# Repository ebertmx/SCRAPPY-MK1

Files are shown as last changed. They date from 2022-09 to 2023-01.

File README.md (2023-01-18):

# SCRAPPY-MK1
 A 3D printed robot arm. View documents in project_files for a complete description.
 
 This arm was developed over a 4 week period as an engineering demonstration. Inspired by a previous project, HUEBERT MK2, SCRAPPY consist mostly of 3D printed components and is controllable over the internet (IoT).

SCRAPPY

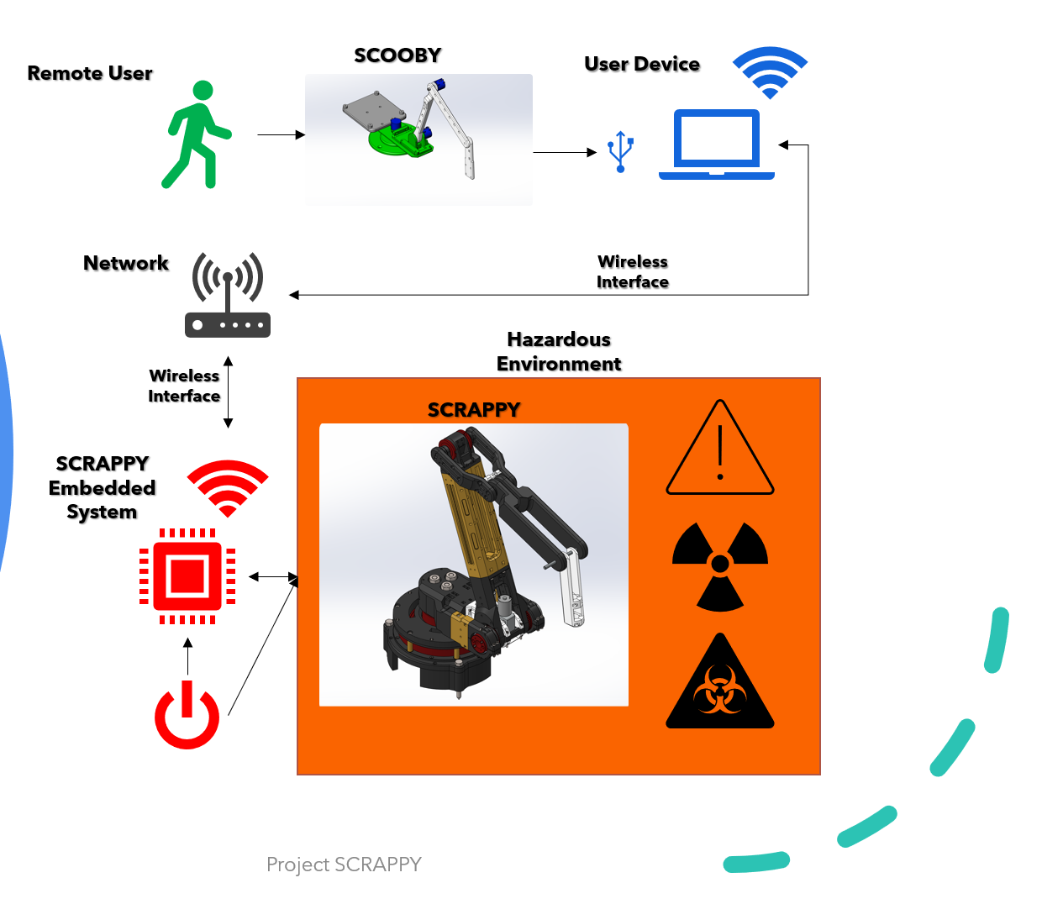
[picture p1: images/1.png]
SCRAPPY - Use Case


The goals of project SCRAPPY were too design and build a robot arm which

1. is highly modular
2. inexpensive
3. had at least 3 DoF
4. could be controlled wireless over a websocket or similar
5. was position and speed controllable
6. used a variety of electrical components (for demonstration purposes)

Other requirements of the specific design can be found in project_files.

The code contained in this respository is designed to run on a 30pin ESP32 Dev module. A python GUI interface is also contained.

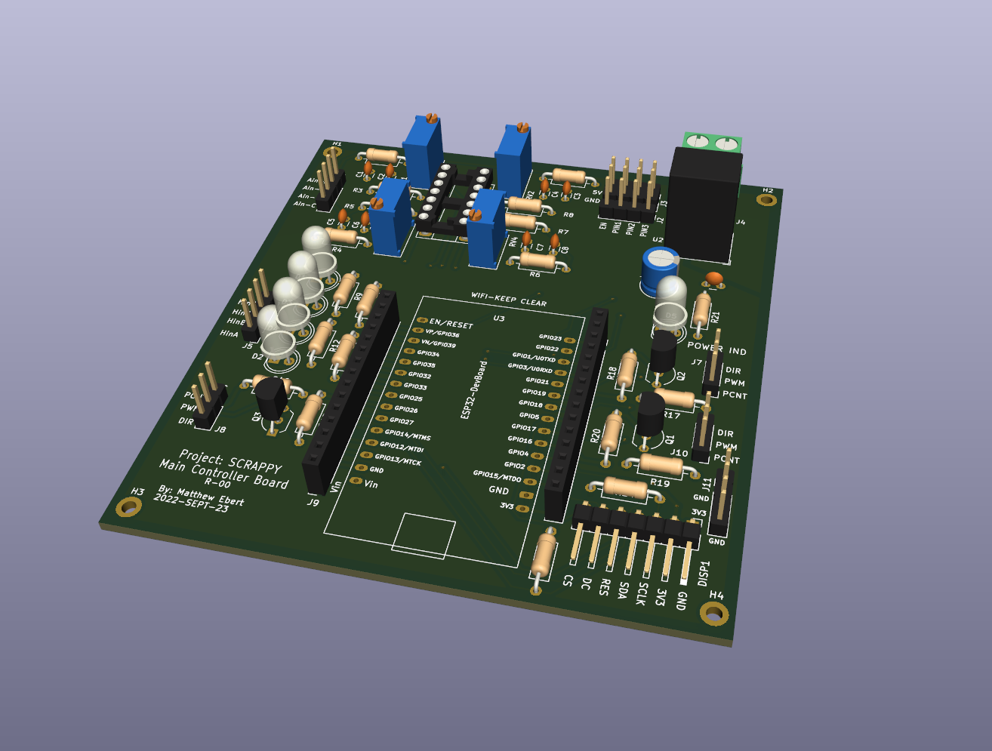
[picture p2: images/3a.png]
PCB design

Electrical
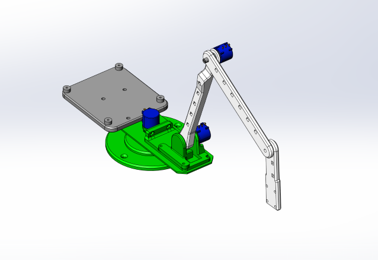
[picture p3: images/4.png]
SCOOBY

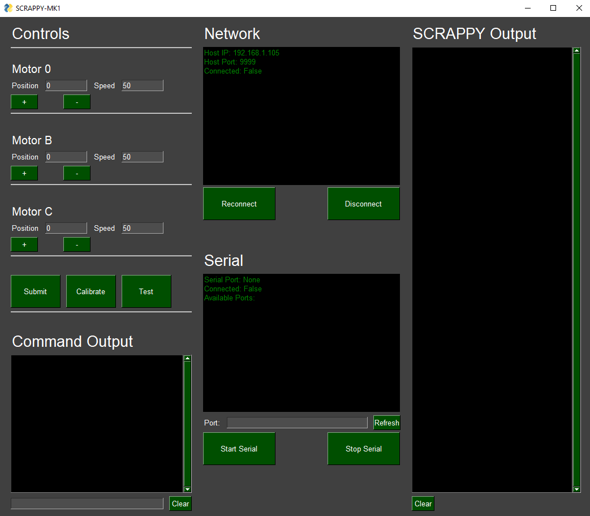
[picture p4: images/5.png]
GUI


This project is ongoing. More details on the use and implementation of this code will be posted when available.

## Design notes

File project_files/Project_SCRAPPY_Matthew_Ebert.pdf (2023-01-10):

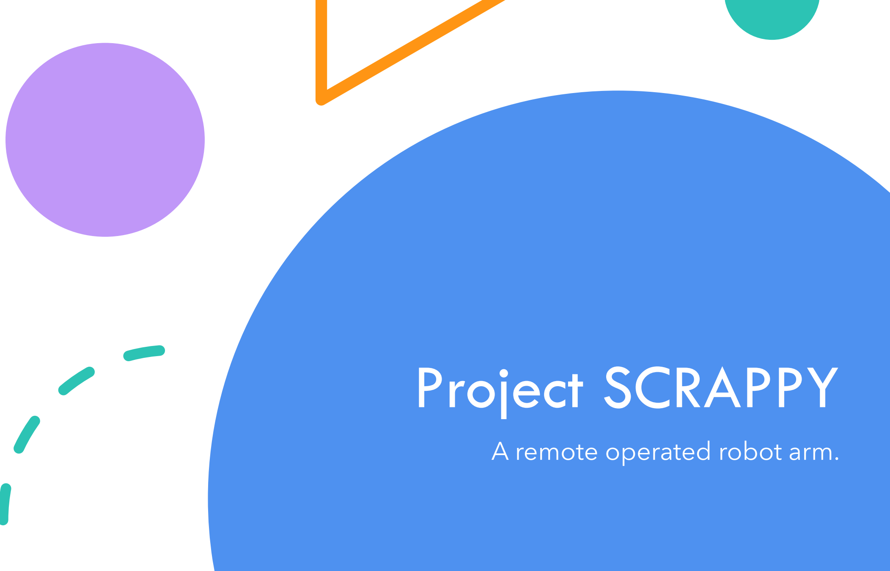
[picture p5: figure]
Project SCRAPPY; A remote operated robot arm.
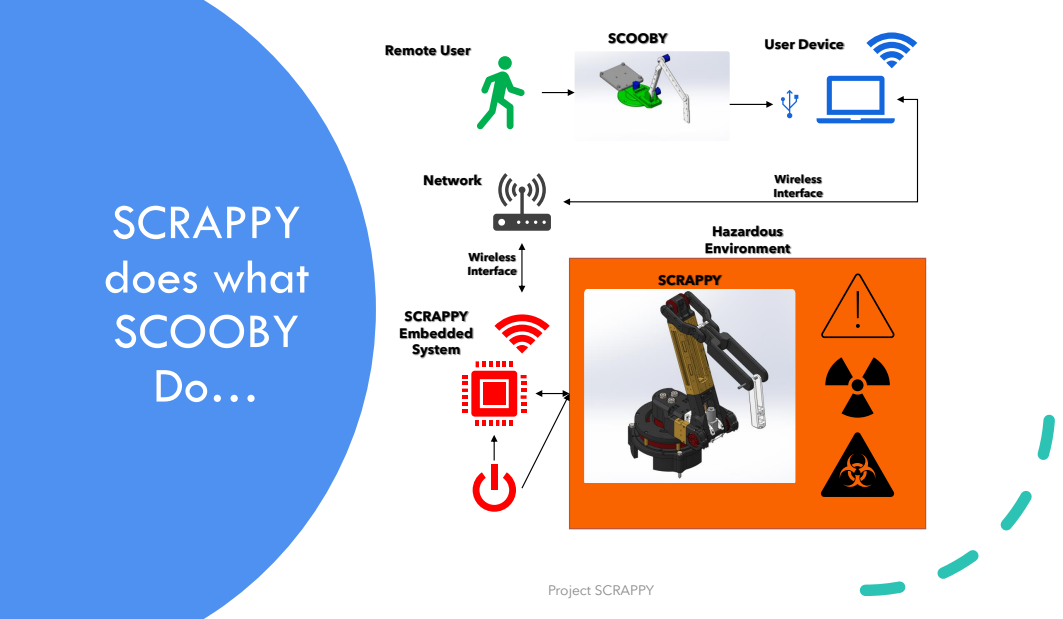
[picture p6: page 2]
SCRAPPY does what SCOOBY Do…; Project SCRAPPY; Remote User; SCOOBY; User Device; Network; SCRAPPY Embedded System; Wireless Interface; Hazardous Environment; SCRAPPY

# Applications

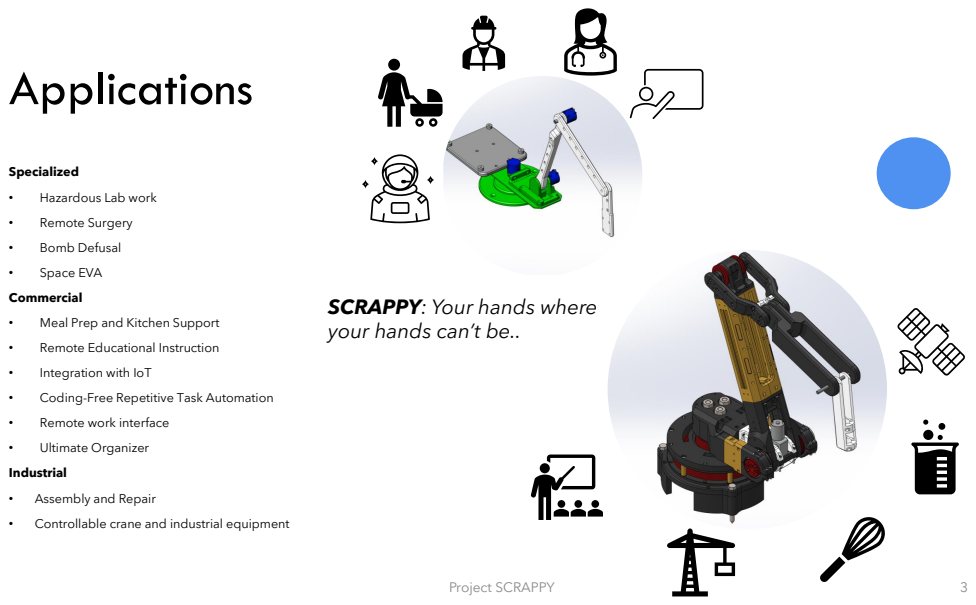
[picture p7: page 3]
Specialized; • Remote Surgery; • Bomb Defusal; • Space EVA; Commercial; • Ultimate Organizer; Industrial; Project SCRAPPY

• Hazardous Lab work

SCRAPPY: Your hands where
your hands can’t be..

• Meal Prep and Kitchen Support

• Remote Educational Instruction

• Integration with IoT

• Coding-Free Repetitive Task Automation

• Remote work interface

• Assembly and Repair

• Controllable crane and industrial equipment

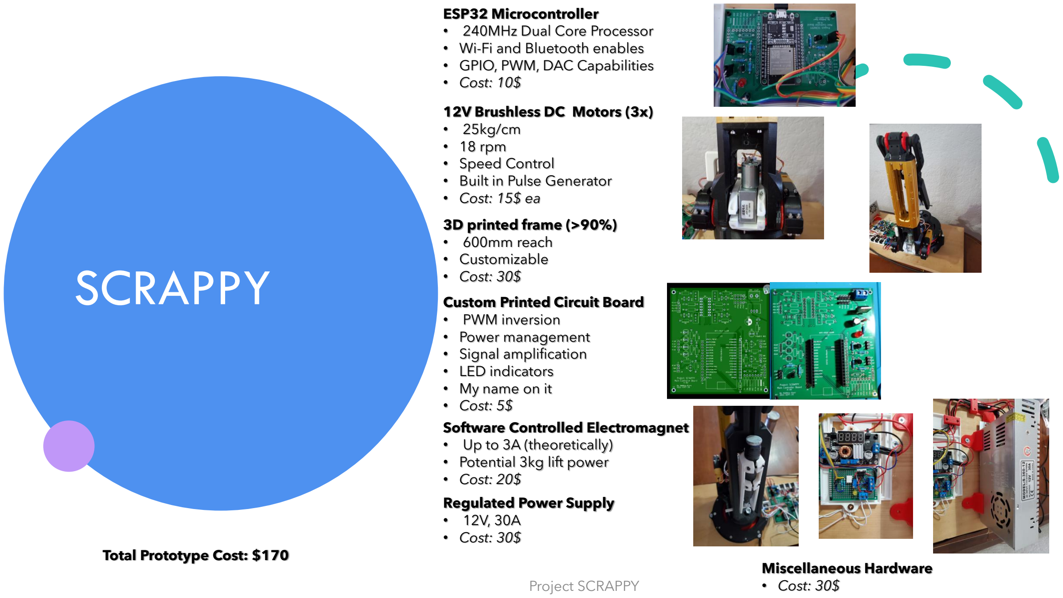
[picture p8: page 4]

# SCRAPPY

Project SCRAPPY

ESP32 Microcontroller
- 240MHz Dual Core Processor
- Wi-Fi and Bluetooth enables
- GPIO, PWM, DAC Capabilities
- Cost: 10$

3D printed frame (>90%)
- 600mm reach
- Customizable
- Cost: 30$

12V Brushless DC Motors (3x)
- 25kg/cm
- 18 rpm
- Speed Control
- Built in Pulse Generator
- Cost: 15$ ea

Custom Printed Circuit Board
- PWM inversion
- Power management
- Signal amplification
- LED indicators
- My name on it
- Cost: 5$

Regulated Power Supply
- 12V, 30A
- Cost: 30$

Miscellaneous Hardware
- Cost: 30$

Software Controlled Electromagnet
- Up to 3A (theoretically)
- Potential 3kg lift power
- Cost: 20$

Total Prototype Cost: $170

# SCRAPPY Design

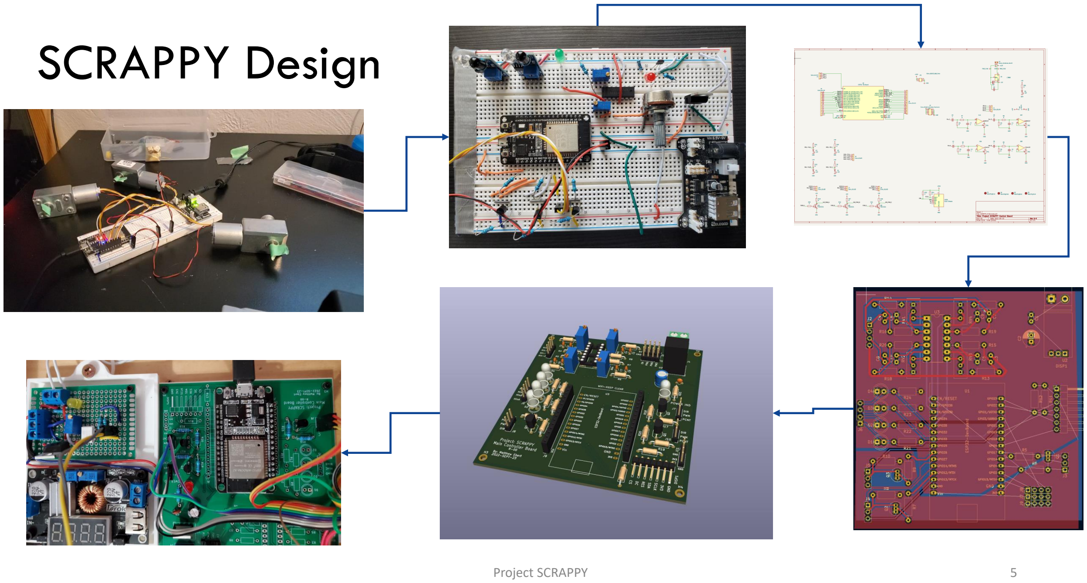
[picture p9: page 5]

# SCRAPPY Design

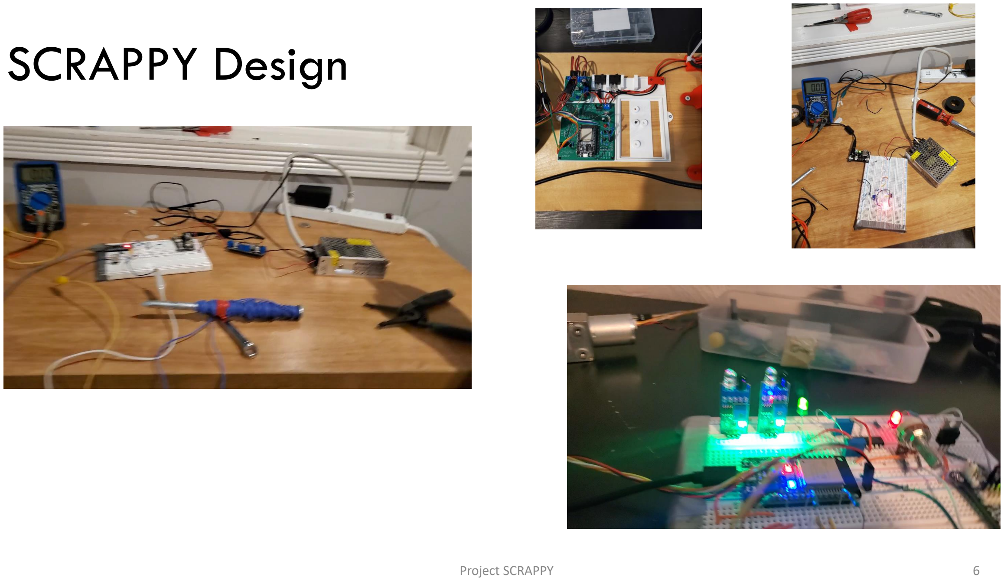
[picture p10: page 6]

# SCRAPPY ASSEBMLY

## 3D printing: Like drawing or writing –

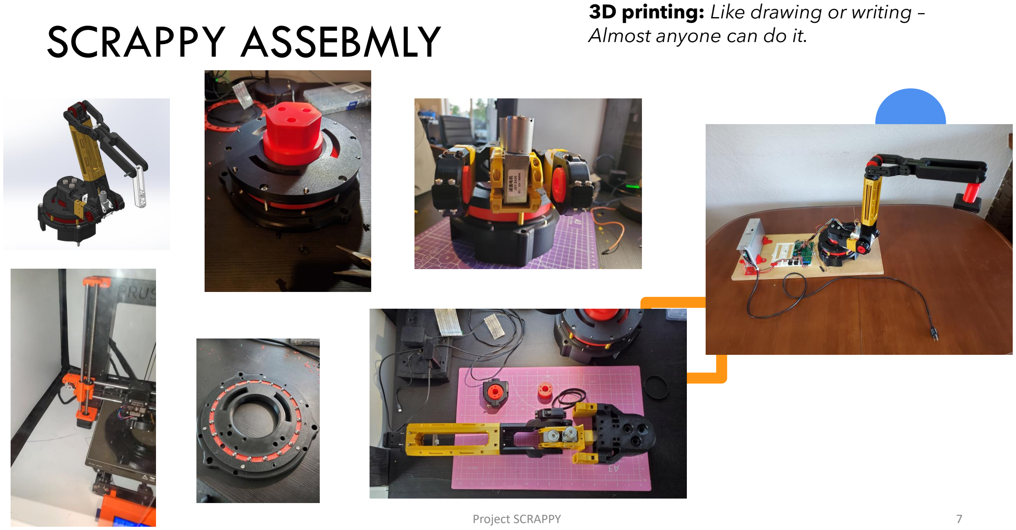
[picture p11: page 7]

Almost anyone can do it.

# User Interface: SCOOBY

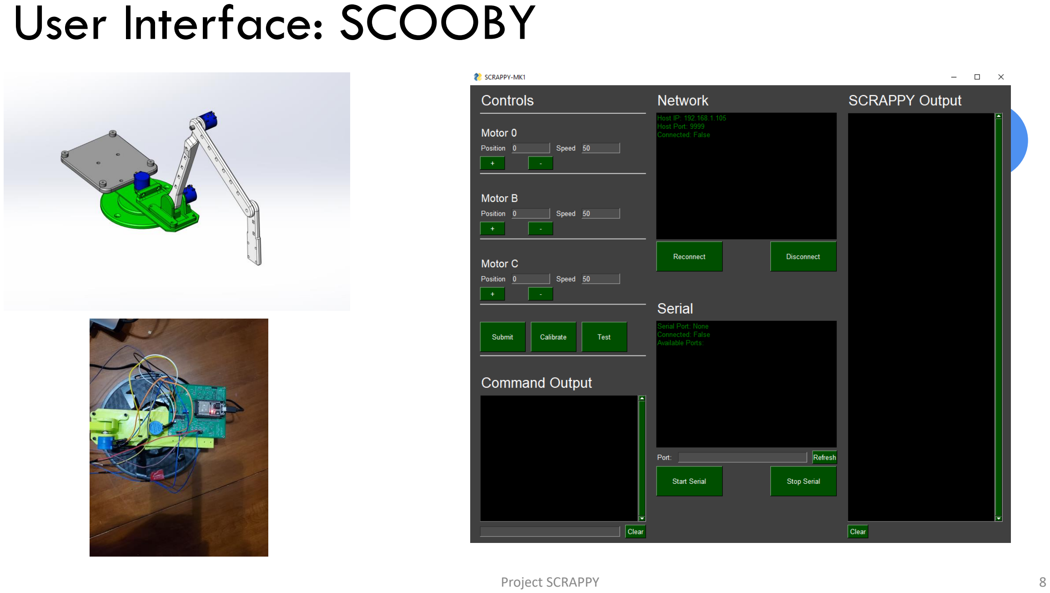
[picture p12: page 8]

# SCRAPPY and ECE

# Mechanically, Scrappy isn’t that

interesting.

# - Very little mechanical analysis needed - 3D printed makes design simple and fast

## This is the easy stuff - no background knowledge required…

# Mecha-tronics is mostly ‘electronics’ - Microcontrollers - Embedded Programming - Motor Control - Power Management - Signal Amplification processing - Control theory

## This is the important stuff- SCRAPPY doesn’t do

anything if this isn’t done right.

# At some point “Engineering is Engineering”

# What do you want to learn… - Microcontrollers and digital design - Control theory - Circuit analysis - Motors and Power electronics - Signal Processing - Material Properties and Quantum

Physics (if you are crazy).

THEN | What do you want to do with it…

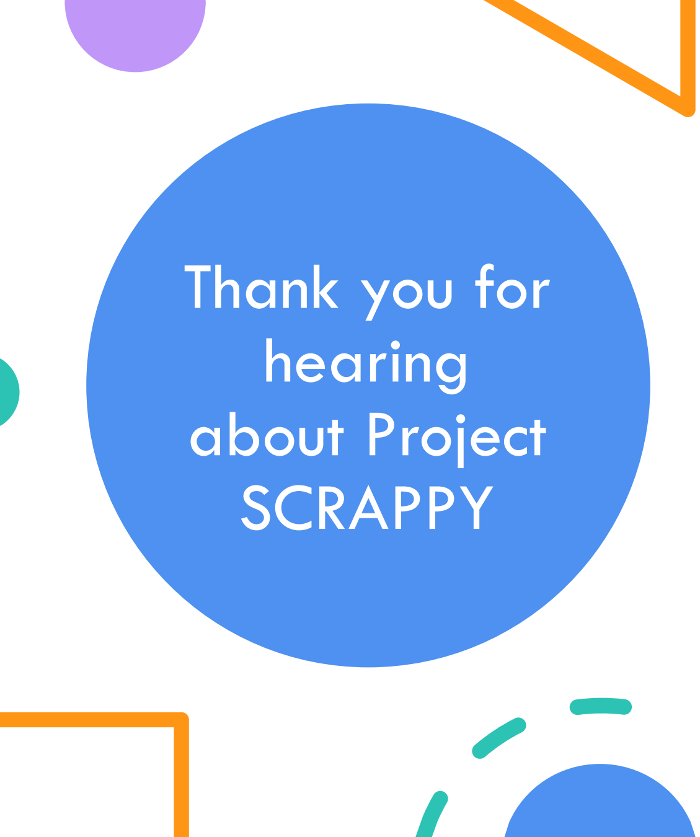
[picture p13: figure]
Thank you for hearing about Project SCRAPPY

# SCRAPPY will be on GitHub Soon at : ebertmx

# Question, Comments, and Feedback

Welcome.

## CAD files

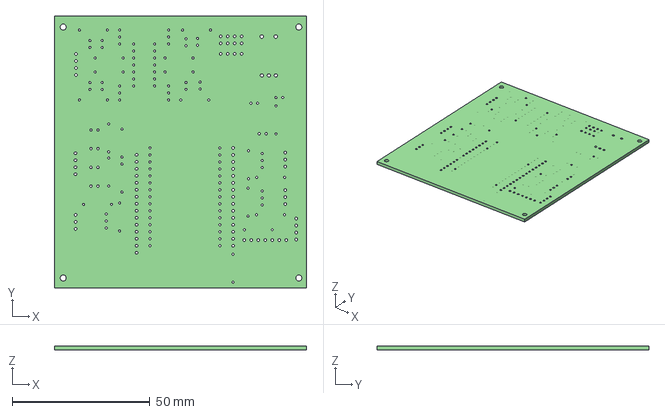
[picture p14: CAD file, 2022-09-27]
Hardware/Electrical/SCRAPPY_PCB/SCRAPPY_PCB.step
91.6 x 98.7 x 1.60 mm

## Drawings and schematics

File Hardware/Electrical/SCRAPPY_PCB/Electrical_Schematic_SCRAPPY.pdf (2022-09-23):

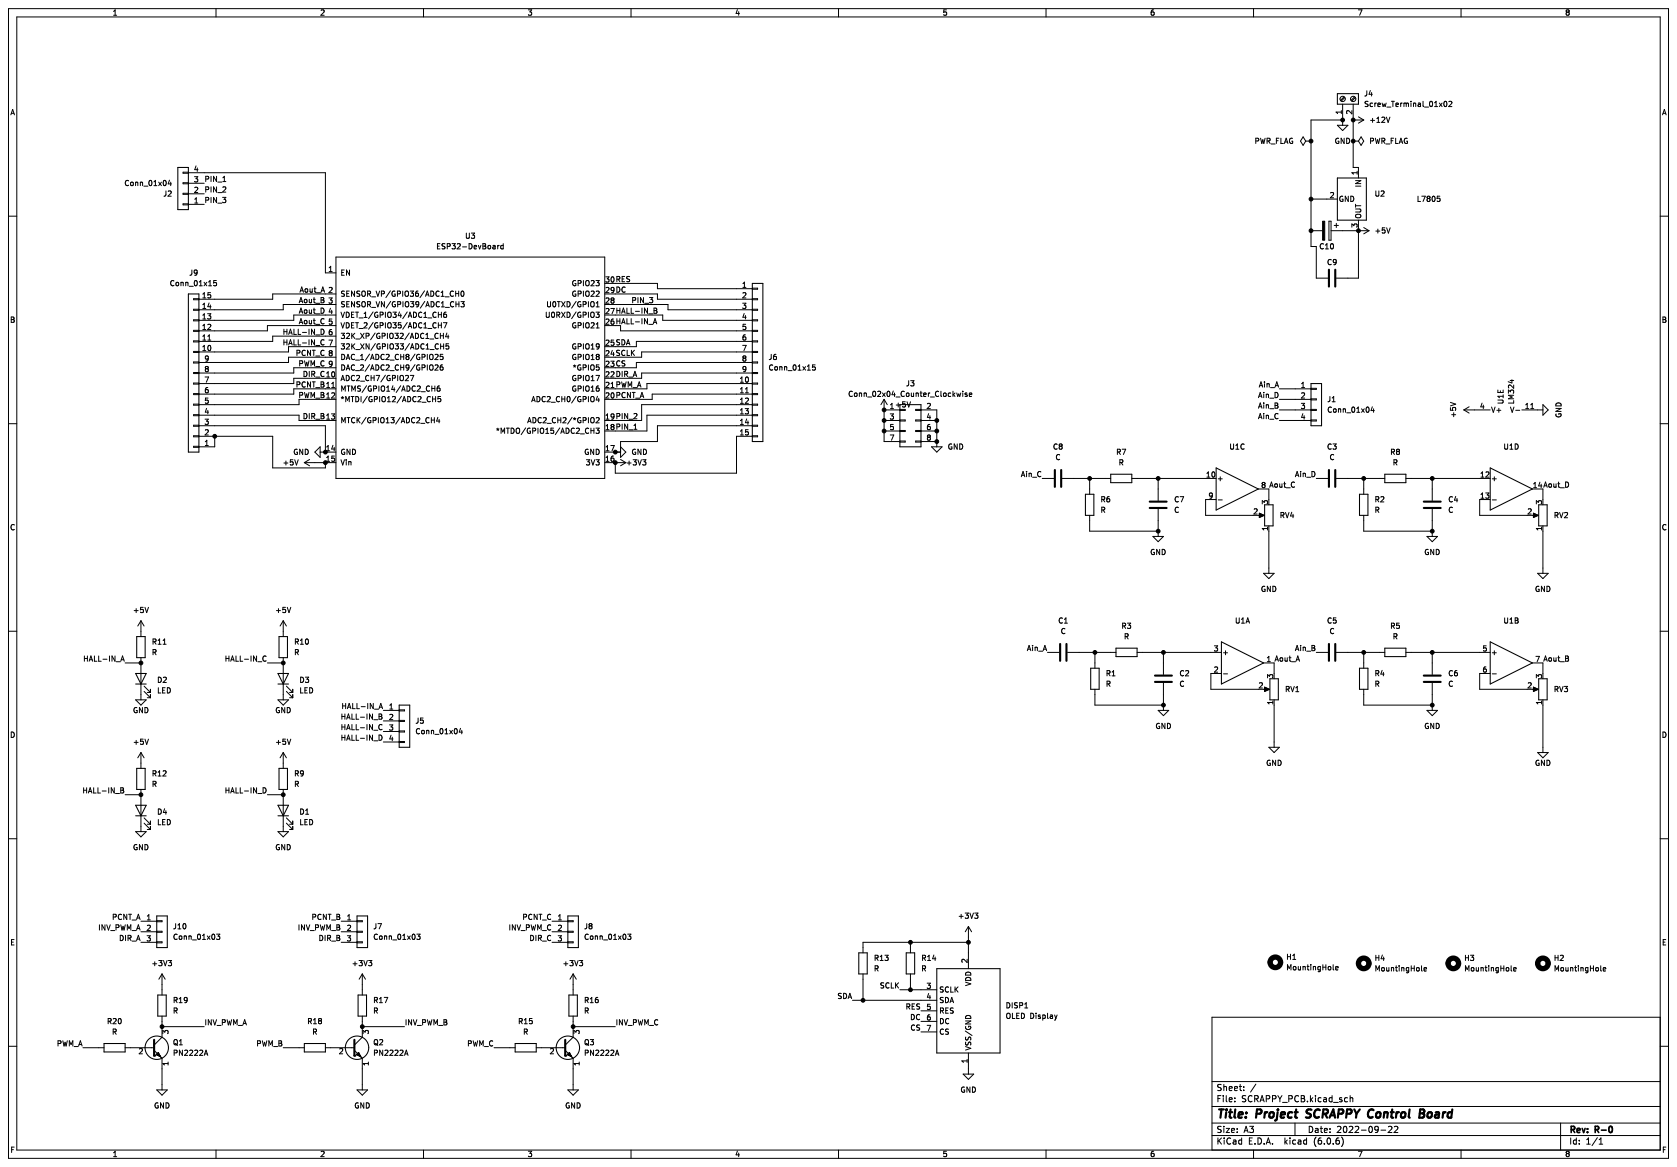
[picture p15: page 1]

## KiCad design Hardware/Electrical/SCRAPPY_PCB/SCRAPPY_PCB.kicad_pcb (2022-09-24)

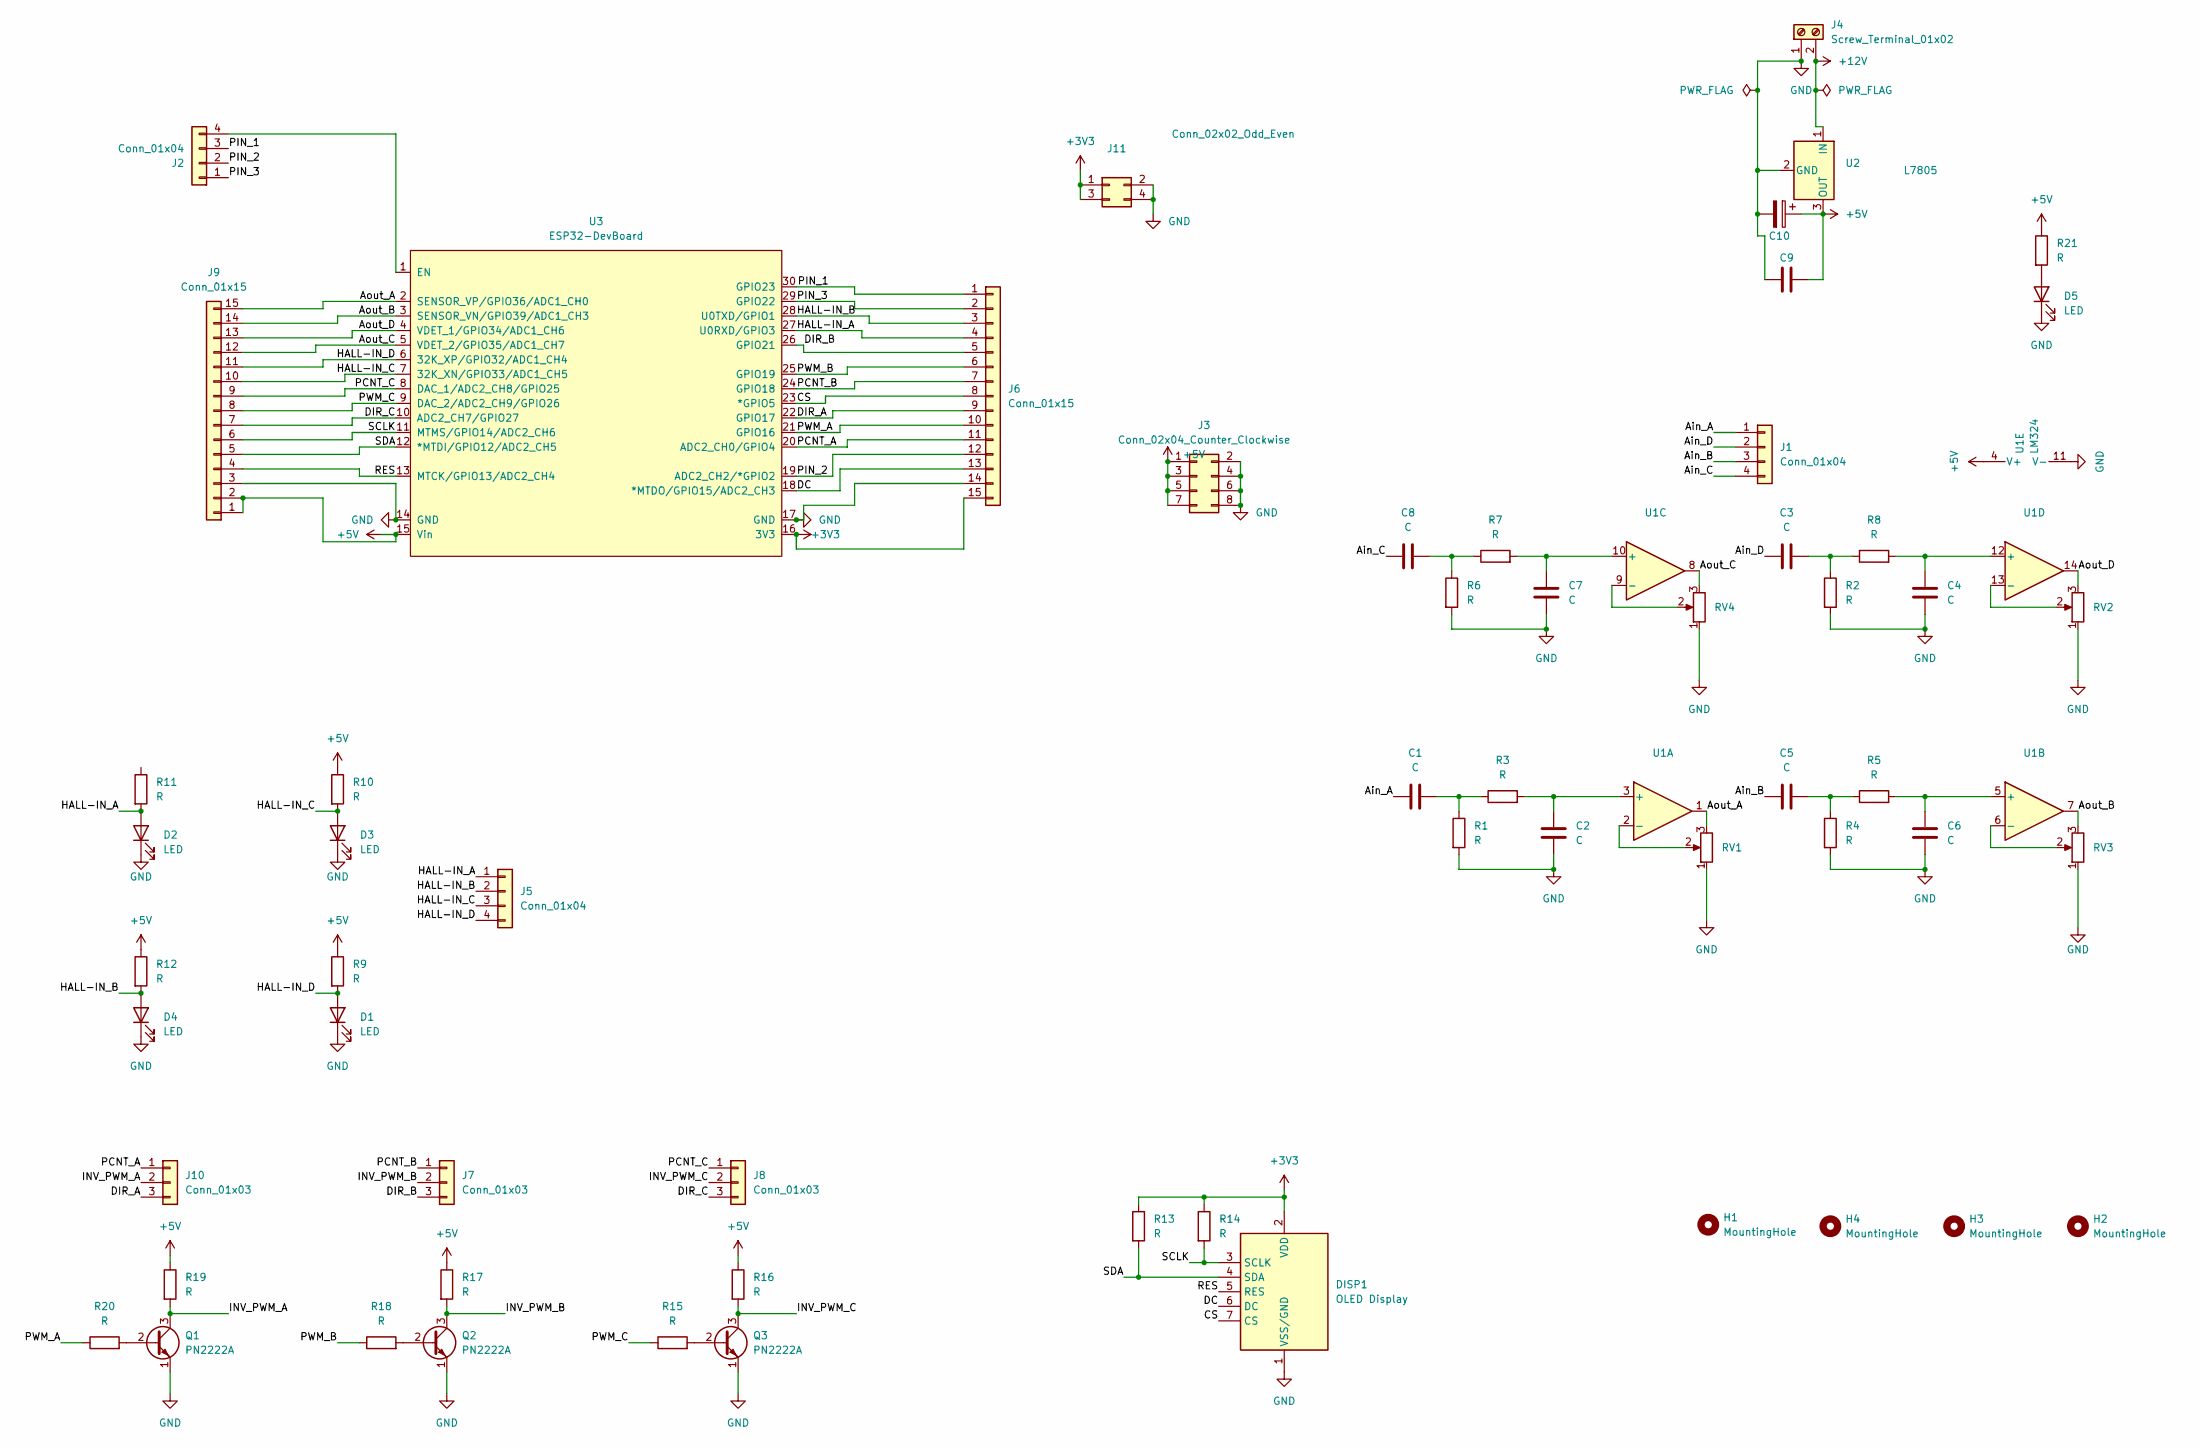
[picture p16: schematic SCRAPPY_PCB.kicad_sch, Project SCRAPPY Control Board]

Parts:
C1, C2, C3, C4, C5, C6, C7, C8, C9: C; C_Disc_D3.0mm_W1.6mm_P2.50mm
C10: C_Polarized; CP_Radial_D6.3mm_P2.50mm
D1, D2, D3, D4, D5: LED; LED_D5.0mm_Clear
DISP1: OLED Display; PinHeader_1x07_P2.54mm_Horizontal
H1, H2, H3, H4: MountingHole; MountingHole_2.2mm_M2_DIN965_Pad
J1, J2, J5: Conn_01x04; PinHeader_1x04_P2.54mm_Vertical
J3: Conn_02x04_Counter_Clockwise; PinHeader_2x04_P2.54mm_Vertical
J4: Screw_Terminal_01x02; TerminalBlock_Phoenix_MKDS-1,5-2-5.08_1x02_P5.08mm_Horizont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
J6, J9: Conn_01x15; PinSocket_1x15_P2.54mm_Vertical
J7, J8, J10: Conn_01x03; PinHeader_1x03_P2.54mm_Vertical
J11: Conn_02x02_Odd_Even; PinHeader_1x04_P2.54mm_Vertical
Q1, Q2, Q3: PN2222A; TO-92_Inline_Wide
R1, R2, R3, R4, R5, R6, R7, R8, R9, R10, R11, R12, R13, R14, R15, R16, R17, R18, R19, R20, R21: R; R_Axial_DIN0207_L6.3mm_D2.5mm_P10.16mm_Horizontal
RV1, RV2, RV3, RV4: R_Potentiometer; Potentiometer_Bourns_3296W_Vertical
U1: LM324; DIP-14_W7.62mm_Socket_LongPads
U2: L7805; Converter_DCDC_RECOM_R-78B-2.0_THT
U3: ESP32-DevBoard

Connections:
+3V3: DISP1.2 (VDD), J6.15, J11.1, J11.3, R13.1, R14.1, U3.16 (3V3)
+5V: C9.2, C10.1, J3.1, J3.3, J3.5, J3.7, J9.1, J9.2, R9.1, R10.1, R12.1, R16.1, R17.1, R19.1, R21.1, U1.4 (V+), U2.3 (OUT), U3.15 (Vin)
+12V: J4.2, U2.1 (IN)
/Ain_A: C1.1, J1.1
/Ain_B: C5.1, J1.3
/Ain_C: C8.1, J1.4
/Ain_D: C3.1, J1.2
/Aout_A: J9.15, RV1.3, U1.1, U3.2 (SENSOR_VP/GPIO36/ADC1_CH0)
/Aout_B: J9.14, RV3.3, U1.7, U3.3 (SENSOR_VN/GPIO39/ADC1_CH3)
/Aout_C: J9.12, RV4.3, U1.8, U3.5 (VDET_2/GPIO35/ADC1_CH7)
/Aout_D: J9.13, RV2.3, U1.14, U3.4 (VDET_1/GPIO34/ADC1_CH6)
/CS: DISP1.7 (CS), J6.8, U3.23 (*GPIO5)
/DC: DISP1.6 (DC), J6.13, U3.18 (*MTDO/GPIO15/ADC2_CH3)
/DIR_A: J6.9, J10.3, U3.22 (GPIO17)
/DIR_B: J6.5, J7.3, U3.26 (GPIO21)
/DIR_C: J8.3, J9.7, U3.10 (ADC2_CH7/GPIO27)
/HALL-IN_A: D2.2 (A), J5.1, J6.4, R11.2, U3.27 (U0RXD/GPIO3)
/HALL-IN_B: D4.2 (A), J5.2, J6.3, R12.2, U3.28 (U0TXD/GPIO1)
/HALL-IN_C: D3.2 (A), J5.3, J9.10, R10.2, U3.7 (32K_XN/GPIO33/ADC1_CH5)
/HALL-IN_D: D1.2 (A), J5.4, J9.11, R9.2, U3.6 (32K_XP/GPIO32/ADC1_CH4)
/INV_PWM_A: J10.2, Q1.3 (C), R19.2
/INV_PWM_B: J7.2, Q2.3 (C), R17.2
/INV_PWM_C: J8.2, Q3.3 (C), R16.2
/PCNT_A: J6.11, J10.1, U3.20 (ADC2_CH0/GPIO4)
/PCNT_B: J6.7, J7.1, U3.24 (GPIO18)
/PCNT_C: J8.1, J9.9, U3.8 (DAC_1/ADC2_CH8/GPIO25)
/PIN_1: J2.3, J6.1, U3.30 (GPIO23)
/PIN_2: J2.2, J6.12, U3.19 (ADC2_CH2/*GPIO2)
/PIN_3: J2.1, J6.2, U3.29 (GPIO22)
/PWM_A: J6.10, R20.1, U3.21 (GPIO16)
/PWM_B: J6.6, R18.1, U3.25 (GPIO19)
/PWM_C: J9.8, R15.1, U3.9 (DAC_2/ADC2_CH9/GPIO26)
/RES: DISP1.5 (RES), J9.4, U3.13 (MTCK/GPIO13/ADC2_CH4)
/SCLK: DISP1.3 (SCLK), J9.6, R14.2, U3.11 (MTMS/GPIO14/ADC2_CH6)
/SDA: DISP1.4 (SDA), J9.5, R13.2, U3.12 (*MTDI/GPIO12/ADC2_CH5)
GND: C2.1, C4.1, C6.1, C7.1, C9.1, C10.2, D1.1 (K), D2.1 (K), D3.1 (K), D4.1 (K), D5.1 (K), DISP1.1 (VSS/GND), J3.2, J3.4, J3.6, J3.8, J4.1, J6.14, J9.3, J11.2, J11.4, Q1.1 (E), Q2.1 (E), Q3.1 (E), R1.2, R2.2, R4.2, R6.2, RV1.1, RV2.1, RV3.1, RV4.1, U1.11 (V-), U2.2 (GND), U3.14 (GND), U3.17 (GND)
unnamed: C1.2, R1.1, R3.1
unnamed: C2.2, R3.2, U1.3 (+)
unnamed: C3.2, R2.1, R8.1
unnamed: C4.2, R8.2, U1.12 (+)
unnamed: C5.2, R4.1, R5.1
unnamed: C6.2, R5.2, U1.5 (+)
unnamed: C7.2, R7.2, U1.10 (+)
unnamed: C8.2, R6.1, R7.1
unnamed: D5.2 (A), R21.2
unnamed: J2.4, U3.1 (EN)
unnamed: Q1.2 (B), R20.2
unnamed: Q2.2 (B), R18.2
unnamed: Q3.2 (B), R15.2
unnamed: RV1.2, U1.2 (-)
unnamed: RV2.2, U1.13 (-)
unnamed: RV3.2, U1.6 (-)
unnamed: RV4.2, U1.9 (-)

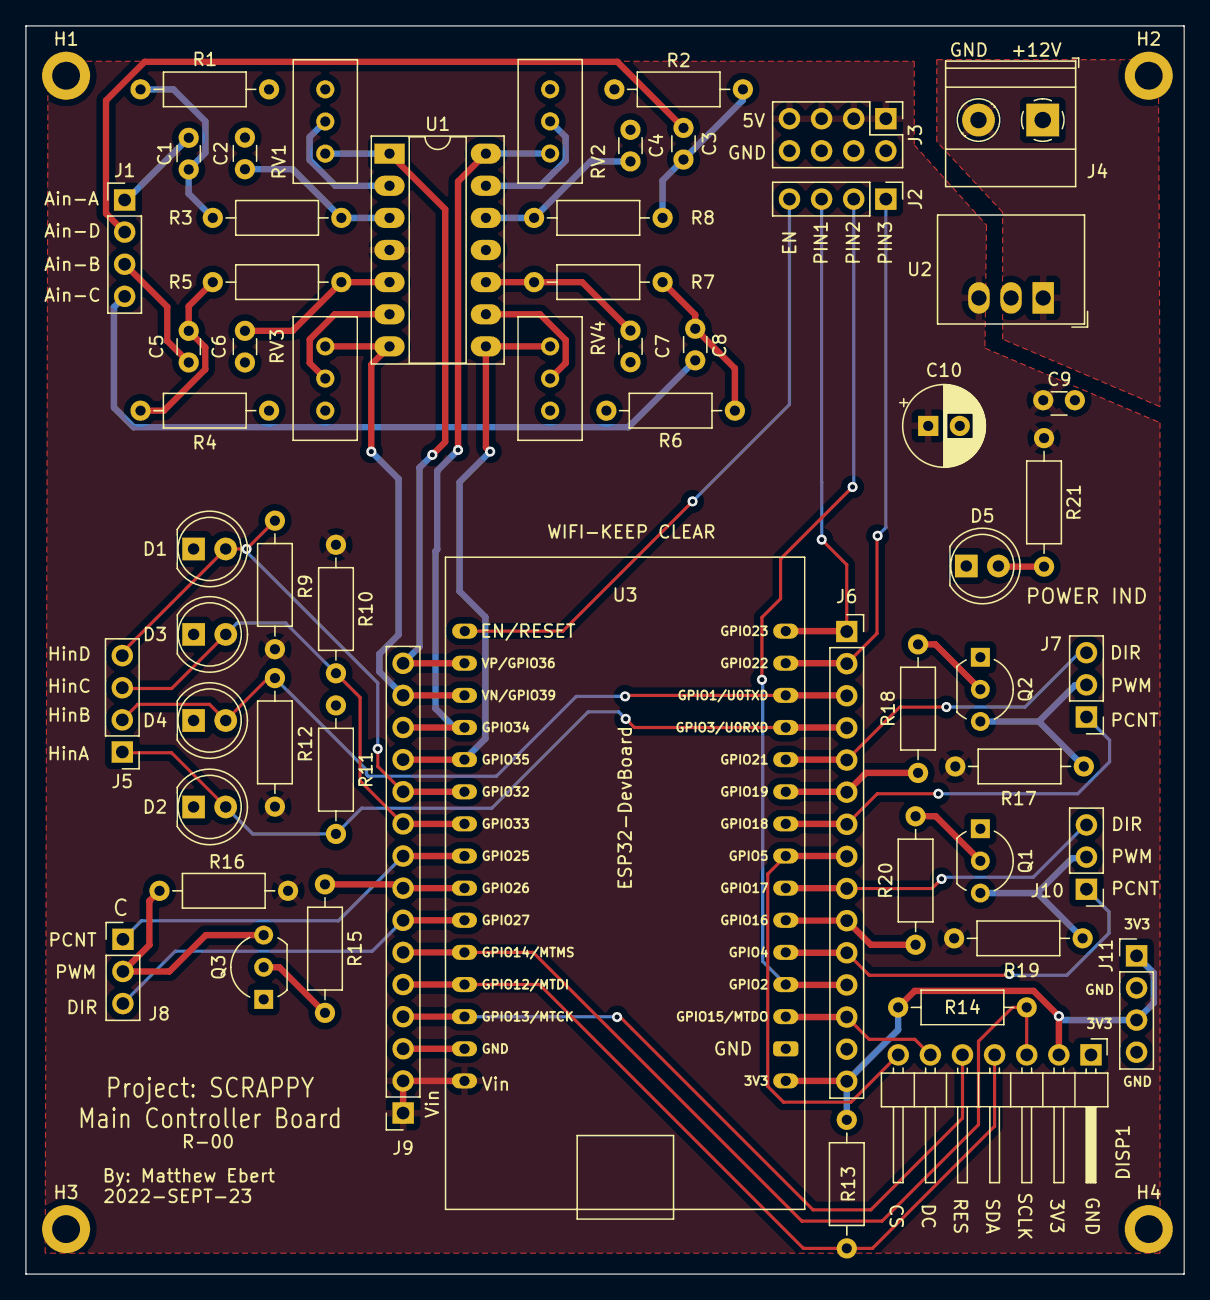
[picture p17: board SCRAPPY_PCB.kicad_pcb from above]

Board: 2 copper layers, 91.6 x 98.7 mm, 62 parts (0 on the bottom side), 53 nets.

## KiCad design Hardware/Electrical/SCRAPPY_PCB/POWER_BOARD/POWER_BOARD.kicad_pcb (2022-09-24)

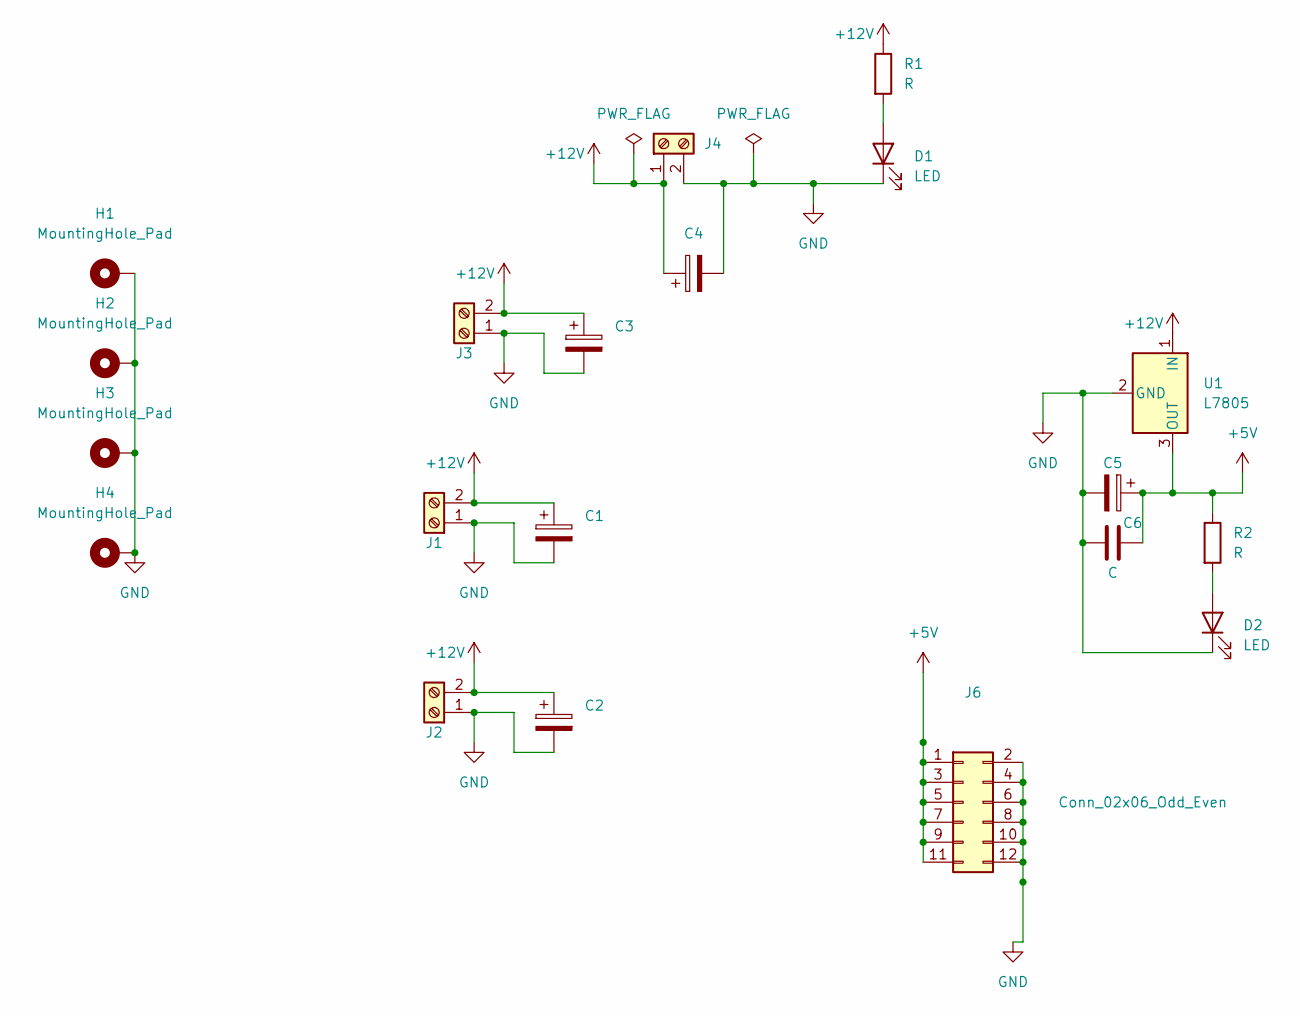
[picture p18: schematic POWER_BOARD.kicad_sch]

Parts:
C1, C2, C3, C5: C_Polarized; CP_Radial_D6.3mm_P2.50mm
C4: C_Polarized; CP_Radial_D10.0mm_P5.00mm
C6: C; C_Disc_D5.0mm_W2.5mm_P2.50mm
D1, D2: LED; LED_D5.0mm
H1, H2, H3, H4: MountingHole_Pad; MountingHole_2.2mm_M2_DIN965_Pad
J1, J2, J3, J4: Screw_Terminal_01x02; TerminalBlock_Phoenix_MKDS-1,5-2_1x02_P5.00mm_Horizontal
J6: Conn_02x06_Odd_Even; PinHeader_2x06_P2.54mm_Vertical
R1, R2: R; R_Axial_DIN0207_L6.3mm_D2.5mm_P10.16mm_Horizontal
U1: L7805; Converter_DCDC_Murata_OKI-78SR_Vertical

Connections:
+5V: C5.1, C6.2, J6.1, J6.3, J6.5, J6.7, J6.9, J6.11, R2.1, U1.3 (OUT)
+12V: C1.1, C2.1, C3.1, C4.1, J1.2, J2.2, J3.2, J4.1, R1.1, U1.1 (IN)
GND: C1.2, C2.2, C3.2, C4.2, C5.2, C6.1, D1.1 (K), D2.1 (K), H1.1, H2.1, H3.1, H4.1, J1.1, J2.1, J3.1, J4.2, J6.2, J6.4, J6.6, J6.8, J6.10, J6.12, U1.2 (GND)
unnamed: D1.2 (A), R1.2
unnamed: D2.2 (A), R2.2

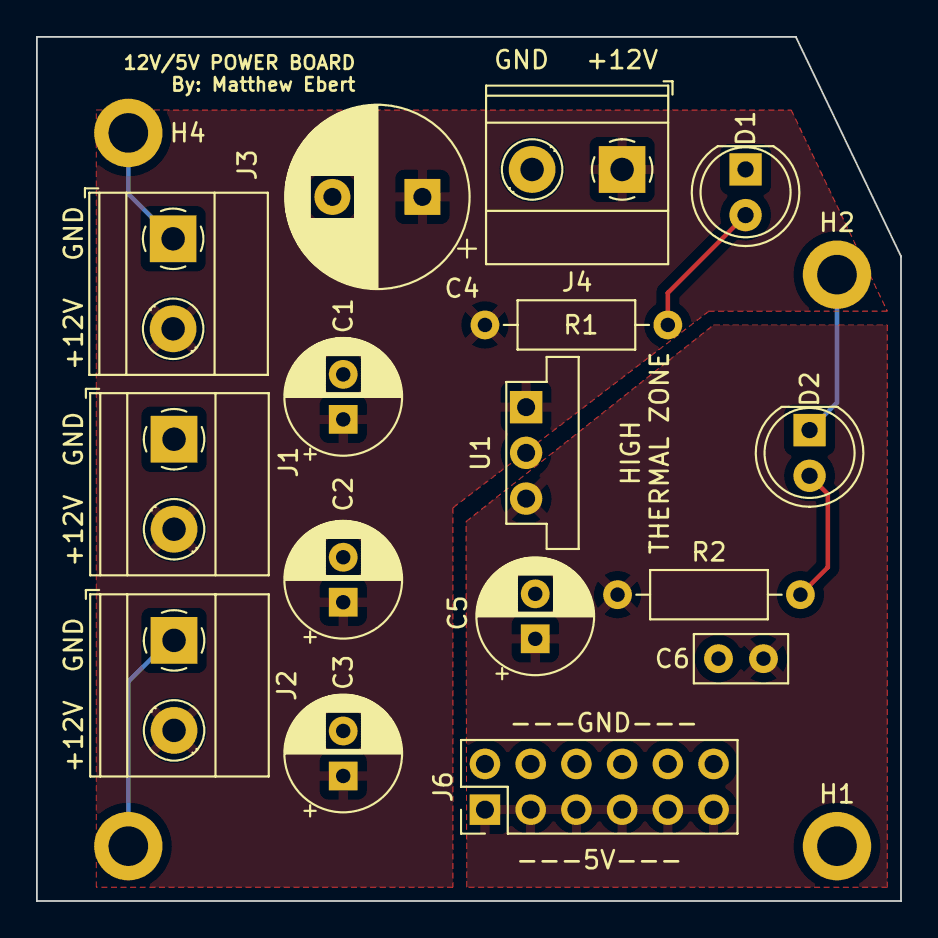
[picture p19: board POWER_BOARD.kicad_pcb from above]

Board: 2 copper layers, 48.0 x 48.0 mm, 20 parts (1 on the bottom side), 5 nets.

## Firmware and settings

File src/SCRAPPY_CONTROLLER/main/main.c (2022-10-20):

/*
 * SPDX-FileCopyrightText: 2021-2022 Espressif Systems (Shanghai) CO LTD
 *
 * SPDX-License-Identifier: Apache-2.0
 */
#include "main.h"
#include "math.h"

// GLOBALS
extern TaskHandle_t xh_MC;
extern QueueHandle_t xMC_queue;

void app_main(void)
{
    //Setup pin for magnet
     gpio_set_direction(2, GPIO_MODE_OUTPUT);
    // esp_log_level_set("*", ESP_LOG_NONE);
    esp_log_level_set("MC-MOTOR", ESP_LOG_NONE);
    ESP_LOGI(SCRP, "SCRAPPY Starting...");

    // esp_log_level_set("*", ESP_LOG_NONE);//disables logging
    ESP_LOGI(SCRP, "Initiating Startup: SCRAPPY");

    // SET UP NETWORK
    ESP_LOGI(WIFI, "Starting Wifi...");
    esp_err_t ret = nvs_flash_init();
    if (ret == ESP_ERR_NVS_NO_FREE_PAGES || ret == ESP_ERR_NVS_NEW_VERSION_FOUND)
    {
        ESP_ERROR_CHECK(nvs_flash_erase());
        ret = nvs_flash_init();
    }
    ESP_ERROR_CHECK(ret);
    wifi_init_sta();
    ESP_LOGI(WIFI, "Wifi Started");

    ESP_LOGI(NET, "Connecting to Network...");
    int sock = connect_to_server();
    if (sock < 0)
    {
        ESP_LOGE(NET, "Connection to server failed");
    }
    else
    {
        ESP_LOGI(NET, "Connection successful");
    }

    ESP_LOGI(SCRP, "Creating Tasks...");
    xTaskCreate(SCRP_MovementControl, "MC", 4086, NULL, 1, &xh_MC);
    xMC_queue = xQueueCreate(10, sizeof(int16_t[7]));
    int count = 0;

    ESP_LOGI(SCRP, "Standing by...");

    static char command[128];
    while (1)
    {
        int len = recv(sock, command, sizeof(command) - 1, 0);
        if (len > 0)
        {
            int16_t intArgs[] = {'x', 0, 0, 0, 0, 0, 0};
            command[len] = 0; // Null-terminate whatever we received and treat like a string
            ESP_LOGI(SCRP, "Received %d bytes from %s:", len, HOST_IP_ADDR);
            ESP_LOGI(SCRP, "%s", command);
            ESP_ERROR_CHECK(parseCommand(command, len, intArgs));
            if (intArgs[0] == 'M'){
                gpio_set_level(2, intArgs[1]);
            } else {
                xQueueSendToBack(xMC_queue, (void *)&(intArgs), portMAX_DELAY);
            }
            memset(command, 0, 128);
        }
        vTaskDelay(10 / portTICK_RATE_MS);
    }
}

/**************************WIFIANDNETWORK**************************/

int16_t charToInt16(char c)
{

    switch (c)
    {
    case '9':
        return 9;
    case '8':
        return 8;
    case '7':
        return 7;
    case '6':
        return 6;
    case '5':
        return 5;
    case '4':
        return 4;
    case '3':
        return 3;
    case '2':
        return 2;
    case '1':
        return 1;
    case '0':
        return 0;
    }
    return 0;
}

esp_err_t parseCommand(char *command, int len, int16_t args[])
{
    int parseArgs = 1;
    int curArg = 6;
    int argIndex = 0;
    char c;
    int16_t tempnum = 0;

    ESP_LOGI(SCRP, "Parsing Command string of length: %d", len);
    args[curArg] = 0;

    for (int i = len - 1; i >= 0; i--)
    {
        c = command[i];
        // printf("c= %c\n", c);
        if (parseArgs)
        {
            if (c == ',' || c == ':')
            {
                ESP_LOGI(SCRP, "Parsed Coordinate for Arg = %d, value = %d", curArg, args[curArg]);
                curArg--;
                args[curArg] = 0;
                argIndex = 0;

                if (c == ':')
                {
                    parseArgs = 0;
                    c = command[i - 1];
                    args[0] = (char) c;
                    ESP_LOGI(SCRP, "Parsed Coordinate for Arg = %d, value = %d", curArg, args[curArg]);
                    return ESP_OK;
                }
                continue;
            }
            if(c =='-'){
                args[curArg]*= -1;
                continue;
            }

            tempnum = charToInt16(c);
            args[curArg] += tempnum * pow(10, argIndex);
            //printf("args[][%d] = %d \n", argIndex, args[curArg]);
            argIndex++;
        }
    }
    return ESP_OK;
}

int connect_to_server()
{
    char host_ip[] = HOST_IP_ADDR;
    int addr_family = 0;
    int ip_protocol = 0;
    struct sockaddr_in dest_addr;
    inet_pton(AF_INET, host_ip, &dest_addr.sin_addr);
    dest_addr.sin_family = AF_INET;
    dest_addr.sin_port = htons(PORT);
    addr_family = AF_INET;
    ip_protocol = IPPROTO_IP;

    int sock = socket(addr_family, SOCK_STREAM, 0);
    int flags = fcntl(sock, F_GETFL);
    fcntl(sock, F_SETFL, flags | O_NONBLOCK);
    if (sock < 0)
    {
        ESP_LOGE(NET, "Unable to create socket: errno %d", errno);
        return -1;
    }
    ESP_LOGI(NET, "Socket created, connecting to %s:%d", host_ip, PORT);

    int err = connect(sock, (struct sockaddr *)&dest_addr, sizeof(dest_addr));

    return sock;
}

static void event_handler(void *arg, esp_event_base_t event_base,
                          int32_t event_id, void *event_data)
{
    if (event_base == WIFI_EVENT && event_id == WIFI_EVENT_STA_START)
    {
        esp_wifi_connect();
    }
    else if (event_base == WIFI_EVENT && event_id == WIFI_EVENT_STA_DISCONNECTED)
    {
        if (s_retry_num < EXAMPLE_ESP_MAXIMUM_RETRY)
        {
            esp_wifi_connect();
            s_retry_num++;
            ESP_LOGI(WIFI, "retry to connect to the AP");
        }
        else
        {
            xEventGroupSetBits(s_wifi_event_group, WIFI_FAIL_BIT);
        }
        ESP_LOGI(WIFI, "connect to the AP fail");
    }
    else if (event_base == IP_EVENT && event_id == IP_EVENT_STA_GOT_IP)
    {
        ip_event_got_ip_t *event = (ip_event_got_ip_t *)event_data;
        ESP_LOGI(WIFI, "got ip:" IPSTR, IP2STR(&event->ip_info.ip));
        s_retry_num = 0;
        xEventGroupSetBits(s_wifi_event_group, WIFI_CONNECTED_BIT);
    }
}

void wifi_init_sta(void)
{
    s_wifi_event_group = xEventGroupCreate();

    ESP_ERROR_CHECK(esp_netif_init());

    ESP_ERROR_CHECK(esp_event_loop_create_default());
    esp_netif_create_default_wifi_sta();

    wifi_init_config_t cfg = WIFI_INIT_CONFIG_DEFAULT();
    ESP_ERROR_CHECK(esp_wifi_init(&cfg));

    esp_event_handler_instance_t instance_any_id;
    esp_event_handler_instance_t instance_got_ip;
    ESP_ERROR_CHECK(esp_event_handler_instance_register(WIFI_EVENT,
                                                        ESP_EVENT_ANY_ID,
                                                        &event_handler,
                                                        NULL,
                                                        &instance_any_id));
    ESP_ERROR_CHECK(esp_event_handler_instance_register(IP_EVENT,
                                                        IP_EVENT_STA_GOT_IP,
                                                        &event_handler,
                                                        NULL,
                                                        &instance_got_ip));

    wifi_config_t wifi_config = {
        .sta = {
            .ssid = EXAMPLE_ESP_WIFI_SSID,
            .password = EXAMPLE_ESP_WIFI_PASS,
            /* Authmode threshold resets to WPA2 as default if password matches WPA2 standards (pasword len => 8).
             * If you want to connect the device to deprecated WEP/WPA networks, Please set the threshold value
             * to WIFI_AUTH_WEP/WIFI_AUTH_WPA_PSK and set the password with length and format matching to
             * WIFI_AUTH_WEP/WIFI_AUTH_WPA_PSK standards.
             */
            .threshold.authmode = ESP_WIFI_SCAN_AUTH_MODE_THRESHOLD,
            //  .sae_pwe_h2e = WPA3_SAE_PWE_BOTH,
        },
    };
    ESP_ERROR_CHECK(esp_wifi_set_mode(WIFI_MODE_STA));
    ESP_ERROR_CHECK(esp_wifi_set_config(WIFI_IF_STA, &wifi_config));
    ESP_ERROR_CHECK(esp_wifi_start());

    ESP_LOGI(WIFI, "wifi_init_sta finished.");

    /* Waiting until either the connection is established (WIFI_CONNECTED_BIT) or connection failed for the maximum
     * number of re-tries (WIFI_FAIL_BIT). The bits are set by event_handler() (see above) */
    EventBits_t bits = xEventGroupWaitBits(s_wifi_event_group,
                                           WIFI_CONNECTED_BIT | WIFI_FAIL_BIT,
                                           pdFALSE,
                                           pdFALSE,
                                           portMAX_DELAY);

    /* xEventGroupWaitBits() returns the bits before the call returned, hence we can test which event actually
     * happened. */
    if (bits & WIFI_CONNECTED_BIT)
    {
        ESP_LOGI(WIFI, "connected to ap SSID:%s password:%s",
                 EXAMPLE_ESP_WIFI_SSID, EXAMPLE_ESP_WIFI_PASS);
    }
    else if (bits & WIFI_FAIL_BIT)
    {
        ESP_LOGI(WIFI, "Failed to connect to SSID:%s, password:%s",
                 EXAMPLE_ESP_WIFI_SSID, EXAMPLE_ESP_WIFI_PASS);
    }
    else
    {
        ESP_LOGE(WIFI, "UNEXPECTED EVENT");
    }
}

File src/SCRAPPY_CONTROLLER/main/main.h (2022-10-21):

#include <stdio.h>
#include "freertos/FreeRTOS.h"
#include "freertos/task.h"
#include "freertos/queue.h"
#include "esp_attr.h"
#include "soc/rtc.h"
#include "driver/gpio.h"
#include "esp_log.h"

#include "movement_control.h"
#include "driver/mcpwm.h"
#include "soc/mcpwm_periph.h"
#include "driver/gpio.h"
#include "driver/pcnt.h"

/*********TAGS*****************/
static const char *SCRP = "SCRAPPY";
static const char *WIFI = "SCRP-WIFI";
static const char *NET = "SCRP-NETWORK";

#define INCLUDE_vTaskSuspend 1

/****************NETWORK************/
#include "sdkconfig.h"
#include <string.h>
#include <unistd.h>
#include <sys/socket.h>
#include <errno.h>
#include <netdb.h> // struct addrinfo
#include <arpa/inet.h>
#include "esp_netif.h"
#include "esp_log.h"
#include "fcntl.h"

#define HOST_IP_ADDR "192.168.150.228"
#define PORT 9999
#define MAX_ARG_LENGTH 16

/**********WIFI*******************/
#include <string.h>
#include "freertos/FreeRTOS.h"
#include "freertos/task.h"
#include "freertos/event_groups.h"
#include "esp_system.h"
#include "esp_wifi.h"
#include "esp_event.h"
#include "esp_log.h"
#include "nvs_flash.h"
#include "lwip/err.h"
#include "lwip/sys.h"

#define EXAMPLE_ESP_WIFI_SSID "DRAGONSCLAW"
#define EXAMPLE_ESP_WIFI_PASS "getoffmywifi"
#define EXAMPLE_ESP_MAXIMUM_RETRY 5
#define ESP_WIFI_SCAN_AUTH_MODE_THRESHOLD WIFI_AUTH_WPA_PSK

/* FreeRTOS event group to signal when we are connected*/
static EventGroupHandle_t s_wifi_event_group;
/* The event group allows multiple bits for each event, but we only care about two events:
 * - we are connected to the AP with an IP
 * - we failed to connect after the maximum amount of retries */
#define WIFI_CONNECTED_BIT BIT0
#define WIFI_FAIL_BIT BIT1
static int s_retry_num = 0;

// FUNCTIONS
int16_t charToInt16(char c);
void convertToInts(char args[16][16], int numArgs, int16_t intArgs[]);
int parseCommand(char *command, int len, int16_t args[7]);
int connect_to_server();

static void event_handler(void *arg, esp_event_base_t event_base,
                          int32_t event_id, void *event_data);
void wifi_init_sta(void);

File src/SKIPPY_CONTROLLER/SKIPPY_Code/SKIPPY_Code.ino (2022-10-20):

/*
Control program for SCOOBY to read positional sensor data, average it and send it to
SCRAPPY's control system
*/


#include <Arduino.h>
#include <string.h>
#include <math.h>

// Global constants
// interval of time to average positional sensor values for
unsigned long interval = 15;
String positional_character = "p";
char final_character = '\n';

int link0_pin = 36;
int link1_pin = 35;
int link2_pin = 34; 


int readQvalue(String pinN);
bool checkbutton(int pin);


bool sending = false;
int magnet = false;

void setup()
{
  // Set serial to a baud rate of 115200 and configure analog and digital pins
  // Analog pins are for the potentiometers
  // Digital pin is for the control button

  Serial.begin(115200);
  pinMode(link0_pin, INPUT);
  pinMode(link1_pin, INPUT);
  pinMode(link2_pin, INPUT);
  //pinMode(3, OUTPUT);
  pinMode(32, INPUT_PULLUP);
  pinMode(3, INPUT_PULLUP);
  pinMode(33, INPUT_PULLUP);
  //digitalWrite(3,1);
  Serial.println("Program Start");
}

void loop()
{
    delay(50);  
  // Instantiate local variables
  unsigned long previousMillis = millis();
  unsigned long currentMillis = millis();
  int n = 0;
  long int a = 0;
  long int b = 0;
  long int c = 0;

  // Average control values over period of time of interval
  while ((currentMillis - previousMillis) < interval)
  {
    a = analogRead(link0_pin) + a;
    b = analogRead(link1_pin) + b;
    c = analogRead(link2_pin) + c;

    n = n + 1;
    currentMillis = millis();
  }

  // Set control values to average over the time interval
  
  //a = 0;
  //b = 0;
  //c = 0;

  a = a / n;
  b = b / n;
  c = c / n;
  
 a = a * 2900 / 4095;
 b = (b-630) * 1545/(4095-630);
c = ((c-52) * 3550/(4095-52));

  // Reset time
  previousMillis = currentMillis;

  // Set control data value
  String control_data = "P:" + String(a) + ',' + String(b) + ',' + String(c) + ',' + "60" + ',' + "90" + ',' + "70" + final_character;
  
  //Set calibration data
  String calibration_data = "C:" + String(a) + ',' + String(b) + ',' + String(c) + ',' + "50" + ',' + "50" + ',' + "50" + final_character;
    
  // Send control data to control system if SKIPPY's control button is pressed
  
  if (checkbutton(3))
  {
    Serial.println(control_data);
    while (checkbutton(3)){
     continue;
    }
  }

  if (checkbutton(32))
  {
    Serial.println(calibration_data);
    while (checkbutton(32)){
     continue;
    }
  }

  if (checkbutton(33)){
    magnet = !magnet;
    if(magnet){
          Serial.println("M: 1, 0, 0, 0, 0, 0");
    }else{
          Serial.println("M: 0, 0, 0, 0, 0, 0");
    }
        while (checkbutton(33)){
     continue;
    }
  }
  
}

bool checkbutton(int pin) {
  unsigned int state = 0xff;
  int i = 0;
  while (i < 16) {
    i = i + 1;
    state = ((state << 1 | digitalRead(pin) | 0x00)) & 0xff;
  }
  if (0x00 == state) {
    return true;
  }
  else {
    return false;
  }

}

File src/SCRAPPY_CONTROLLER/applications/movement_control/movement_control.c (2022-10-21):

/*  Created: 2022-10-02 By: ebertmx

*Description: This task operates and monitors the movement operations
    of SCRAPPY, a robot arm. It is solely responsible to driving the motors
    and reading sensor data. All other processes must use the
    SCRP_MovementControl
    task to access SCRAPPY's motors
*A list of function and components can be found in movement_control.h
*/
#include "movement_control.h"
// Tasks
TaskHandle_t xh_MC = NULL;

TaskHandle_t xh_MC_Set = NULL;
TaskHandle_t xh_MC_Run = NULL;
TaskHandle_t xh_MC_Stop = NULL;
TaskHandle_t xh_MC_Motors = NULL;
// Queues
QueueHandle_t xMC_queue;
xQueueHandle enc_evt_queue;

// Motor Structs
static xSCRP_motor_t MOTOR0 = {
    .num = 0,
    .pin_pwm = motorpwm0,
    .pin_dir = motordir0,
    .pin_enc = motorenc0,
    .speed = 0,
    .minspeed = 20,
    .Kp = 0.3,
    .error = 0,
    .errorprev = -1,
    .count = 0,
    .signal = 0,
    .direction = 0,
    .position = 0,
    .target = 0,
    .enc_target = 0,
    .enable = false,
    .pwm_io = MCPWM0A,
    .pwm_unit = MCPWM_UNIT_0,
    .pwm_timer = MCPWM_TIMER_0,
    .pwm_gen = MCPWM_OPR_A,
    .enc_dir = PCNT_COUNT_DEC,
    .enc_unit = PCNT_UNIT_0,
    .enc_channel = PCNT_CHANNEL_0};

static xSCRP_motor_t MOTOR1 = {
    .num = 1,
    .pin_pwm = motorpwm1,
    .pin_dir = motordir1,
    .pin_enc = motorenc1,
    .speed = 0,
    .minspeed = 30,
    .Kp = 0.5,
    .error = 0,
    .errorprev = -1,
    .count = 0,
    .signal = 0,
    .direction = 0,
    .position = 0,
    .target = 0,
    .enc_target = 0,
    .enable = false,
    .pwm_io = MCPWM0B,
    .pwm_unit = MCPWM_UNIT_1,
    .pwm_timer = MCPWM_TIMER_0,
    .pwm_gen = MCPWM_OPR_B,
    .enc_dir = PCNT_COUNT_DEC,
    .enc_unit = PCNT_UNIT_1,
    .enc_channel = PCNT_CHANNEL_0};

static xSCRP_motor_t MOTOR2 = {
    .num = 2,
    .pin_pwm = motorpwm2,
    .pin_dir = motordir2,
    .pin_enc = motorenc2,
    .speed = 0,
    .minspeed = 30,
    .Kp = 0.4,
    .error = 0,
    .errorprev = -1,
    .count = 0,
    .signal = 0,
    .direction = 0,
    .position = 0,
    .target = 0,
    .enc_target = 0,
    .enable = false,
    .pwm_io = MCPWM2B,
    .pwm_unit = MCPWM_UNIT_0,
    .pwm_timer = MCPWM_TIMER_2,
    .pwm_gen = MCPWM_OPR_B,
    .enc_dir = PCNT_COUNT_DEC,
    .enc_unit = PCNT_UNIT_2,
    .enc_channel = PCNT_CHANNEL_0};

// Variables
static bool pcnt_isr_installed = false;
static bool STOP = false;
// INTERRUPTS
static void IRAM_ATTR encoder_isr_handler(void *arg)
{
    // ESP_LOGI(MCTAG, "Interrupt");
    int pcnt_unit = (int)arg;
    /* Save the PCNT event type that caused an interrupt
       to pass it to the main program */
    // pcnt_get_event_status(pcnt_unit, &evt.status);
    // printf("Unit: %d    Event: %c", evt.unit, evt.status);
    switch (pcnt_unit)
    {
    case 0:
        MOTOR0.enable = false;
        break;
    case 1:
        MOTOR1.enable = false;
        break;
    case 2:
        MOTOR2.enable = false;
        break;
    }
    BaseType_t xHigherPriorityTaskWoken = pdFALSE;
    vTaskNotifyGiveFromISR(xh_MC_Stop, &xHigherPriorityTaskWoken);
}

//*******************TASKS************************//
/**
 * @brief : Handles Messages and Commands from SCRP main
 *
 * @param args : Nothing
 */
void SCRP_MovementControl(void *args)
{
    ESP_LOGI(MC, "Initiate SCRP Movement Controller");
    enc_evt_t evt;
    enc_evt_queue = xQueueCreate(10, sizeof(enc_evt_t));

    static int16_t rxbuff[7];

    ESP_LOGI(MC, "Initiate Motor Setup");
    ESP_ERROR_CHECK(xMotorSetup(&MOTOR0));
    ESP_ERROR_CHECK(xMotorSetup(&MOTOR1));
    ESP_ERROR_CHECK(xMotorSetup(&MOTOR2));
    ESP_LOGI(MC, "Motor Setup Complete");

    ESP_LOGI(MC, "Creating Tasks");
    xTaskCreatePinnedToCore(MC_Run, "MC_Run", 4086, NULL, tskIDLE_PRIORITY, &xh_MC_Run, 1);
    xTaskCreate(MC_Stop, "MC_Stop", 2048, NULL, 2, &xh_MC_Stop);

    ESP_LOGI(MC, "Standing by...");

    while (1)
    {

        if (xQueueReceive(xMC_queue, &(rxbuff), portMAX_DELAY))
        {
            char code = rxbuff[0];

            ESP_LOGI(MC, "Data Recieved: %d, %d, %d, %d, %d, %d, %d ", code,
                     rxbuff[1],
                     rxbuff[2],
                     rxbuff[3],
                     rxbuff[4],
                     rxbuff[5],
                     rxbuff[6]);

            switch (code)
            {
            case 'P':
                vTaskDelay(10 / portTICK_RATE_MS);
                if (ulTaskNotifyTake(pdTRUE, portMAX_DELAY))
                {

                    MOTOR0.target = rxbuff[1];
                    MOTOR1.target = rxbuff[2];
                    MOTOR2.target = rxbuff[3] - (rxbuff[2]) / MOTOR2_CORR_FACTOR; // compensate for link1 rotation
                    MOTOR0.speed = rxbuff[4];
                    MOTOR1.speed = rxbuff[5];
                    MOTOR2.speed = rxbuff[6];

                    xSetMotor(&MOTOR0);
                    xSetMotor(&MOTOR1);
                    xSetMotor(&MOTOR2);
                    ESP_LOGI(MC, "Motors Set");
                    xTaskNotifyGive(xh_MC_Run);
                }
                break;

            case 'S':
                xTaskNotifyGive(xh_MC_Stop);
                break;

            case 'C':

                MOTOR0.position = rxbuff[1];
                MOTOR1.position = rxbuff[2];
                MOTOR2.position = rxbuff[3] - (rxbuff[2]) / MOTOR2_CORR_FACTOR; // compensate for link1 rotation
                MOTOR0.speed = rxbuff[4];
                MOTOR1.speed = rxbuff[5];
                MOTOR2.speed = rxbuff[6];
                xClearCounter(&MOTOR0);
                xClearCounter(&MOTOR1);
                xClearCounter(&MOTOR2);
                xSetMotor(&MOTOR0);
                xSetMotor(&MOTOR1);
                xSetMotor(&MOTOR2);
                ESP_LOGI(MC, "Calibrated to P = %d,%d,%d", MOTOR0.position, MOTOR1.position, MOTOR2.position);

                break;
            default:
                break;
            }
            memset(rxbuff, 0, 7 * sizeof(int16_t));
        }
    }
}
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

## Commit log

2022-09-21 Initial Project Files
    [REACH_electrical.kicad_pcb, REACH_electrical.kicad_sch, Req_and_Dev-SCRAPPY.xlsx]
2022-09-21 Update Req
    [Req_and_Dev-SCRAPPY.xlsx]
2022-09-21 Added testing and development files for the ESP devices
2022-09-23 Created initial PCB design
    [REACH_electrical.kicad_pcb, REACH_electrical.kicad_sch, SCRAPPY_PCB.kicad_pcb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]
2022-09-23 Updated PCB; Ready for Manufacture
    [SCRAPPY_PCB-B_Cu.gbr, SCRAPPY_PCB-B_Mask.gbr, SCRAPPY_PCB-B_Silkscreen.gbr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]
2022-09-24 Added Power PCB
    [POWER_BOARD-B_Cu.gbr, POWER_BOARD-B_Mask.gbr, POWER_BOARD-B_Silkscreen.gbr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]
2022-09-24 PCB Ordered
2022-09-27 Update design documents
    [Req_and_Dev-SCRAPPY.xlsx, SCRAPPY_PCB.step]
2022-09-27 Updated Docs
    [Req_and_Dev-SCRAPPY.xlsx]
2022-10-02 Updated Build
    [Req_and_Dev-SCRAPPY.xlsx]
2022-10-02 Updated REQS
    [Req_and_Dev-SCRAPPY.xlsx]
2022-10-07 Git Ignore Still not working
    [main.c, main.h, movement_control.c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]
2022-10-09 Updated SCRAPPY CONTROLLER
    Working Simple Motor
2022-10-10 Fixed PCNT counter bugs
    [main.c, movement_control.c]
2022-10-10 Added Calibration code
2022-10-10 Updated Calibration
2022-10-11 Updated Controller with Calibration step
2022-10-11 UPdated Calibrate
2022-10-11 Update Calibration
2022-10-15 Update MovementController for 3 motors
2022-10-15 Buttons and WIP refactor
2022-10-15 Bug fixes with control signal
    [main.c, movement_control.c]
2022-10-17 Updated main for use Still bugs but in decent condition
    [main.c, movement_control.c, movement_control.h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]
2022-10-17 Good state; About to test SKIPPY integration
    [main.c, scrappy_gui.py, scrappy_server.py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]
2022-10-17 Link 1 SKIPPY operational
    [main.c, main.h, movement_control.c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]
2022-10-17 Successful Test with SKIPPY integration
    [main.c]
2022-10-17 Added Skippy Code; Deleted Old Calibration
    [SKIPPY_Code.ino, main.c, main.h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]
2022-10-18 Magnet code
2022-10-20 Magnet button
2022-10-21 Added auto move test button
